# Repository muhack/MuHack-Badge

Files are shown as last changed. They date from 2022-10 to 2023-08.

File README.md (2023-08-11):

# MuHack-Badge
Official repository for MuHack Badge.

Badge startup

The board features an RP2040 as main microcontroller running micropython.
Its job is to setup and stream data from the Bosh Sensor Hub BHI106(B), as well as controlling the LEDs.

```Hardware/``` folder contains the KiCad project

```Software/``` folder contains the BOSS system and the sketches for the ESP32 (WIP)

> **NOTE: The software is still in development, so expect A LOT OF bugs and missing features.**

![Badge rotate](/image/rotate.gif)

## Chagelog v2

 - Added USB connector for the ESP32
 - Added NFC subsystem
 - Completely reworked the power system
 - Added more LEDs for battery status and esp32
 - Added a button for the ESP32
 - WIP: firmware update for better BHI support

## Chagelog v1
 - Initial release

## TODOs:
 - [x] Connect the interrupt line of BHI to the RP2040
 - [x] Invert TX/RX of UART between ESP32 and RP2040
 - [x] Change to a bigger footprint of ESP32 debug port
 - [x] Maybe add two button for boot sel and reset for the ESP32
 - [x] ~~Change~~ Remove battery switch
 - [x] Improve silkscreen text size
 - [x] Add silkscreen label for many things (pinout, battery polarity, etc)
 - [x] Expose BHI's internal I2C and interrupt line (for future sensors)
 - [x] Move I2C pull-up resistor
 - [x] Add leds and diods polarity
 - [x] Remove power inductor (or change to an available one)
 - [ ] ~~Maybe add a way to switch LEDs data line to the ESP32 instead of the RP2040~~
 - [ ] Docs and code comments
 - [x] Remove the D16 Schottky Diode from the battery line
 - [x] Maybe add some more cap to prevent brown-out when disconnecting USB power
 - [ ] Add a method within BHY library to stop every sensor
 - [x] Add NFC subsystem
 - [x] Add USB connector for the ESP32
  
 Special Thanks to:
 @gcammisa and Paolino

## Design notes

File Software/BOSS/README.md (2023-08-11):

# Badge Operating Small System

> **NOTE: The software is still in development, so expect A LOT OF bugs and missing features.**

The calibration process is still in development: there is a small utility to calibrate the sensor, but it is currently disabled from the headless mode.

## How to use

### Serial console
Simply connect the badge to your computer and connect to the serial port with a terminal emulator (e.g. `screen` or `minicom`).

### Headless mode
Turn the badge on without any USB data connection active and select the application you want to run.

Use the button "A" to select the application and the button "B" to start/stop it.

At the moment, there are 4 applications available:
- **Compass**: a simple compass that shows the current orientation of the badge, red arrow **should** points north
- **Accelerometer**: a simple accelerometer that shows the current acceleration on the 3 axis, the led on the "h" show the outwards direction, the led on the "u" show the inwards direction
- **Light show**: a simple light show, thank to the TrickLED library (to quit, reboot the badge)
- **Ball**: simulate the presence of a ball inside the led ring, using the accelerometer

If you leave the badge idle for around 200 seconds, it will automatically start the idle animation: simply pick it up or double tap on it to return to the menu.

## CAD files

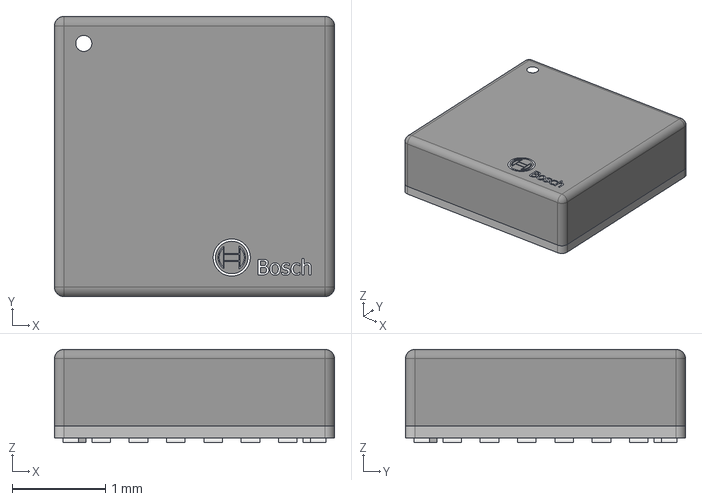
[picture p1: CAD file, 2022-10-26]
Hardware/IC_Bosch Sensortec_BHI160B/eec.models/Bosch_Sensortec_-_BHI160B.step
3.00 x 3.00 x 1.00 mm

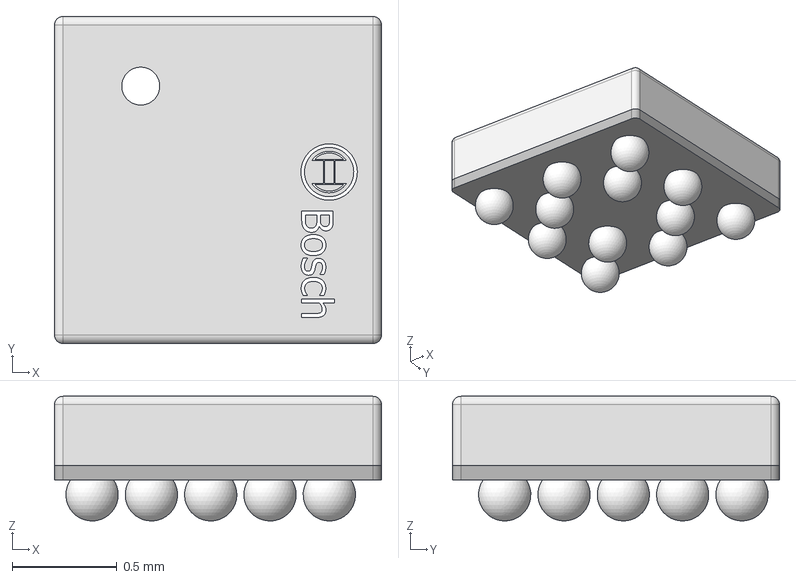
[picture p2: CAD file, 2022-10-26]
Hardware/IC_Bosch Sensortec_BMM150/eec.models/Bosch_Sensortec_-_BMM150.step
1.56 x 1.56 x 0.596 mm

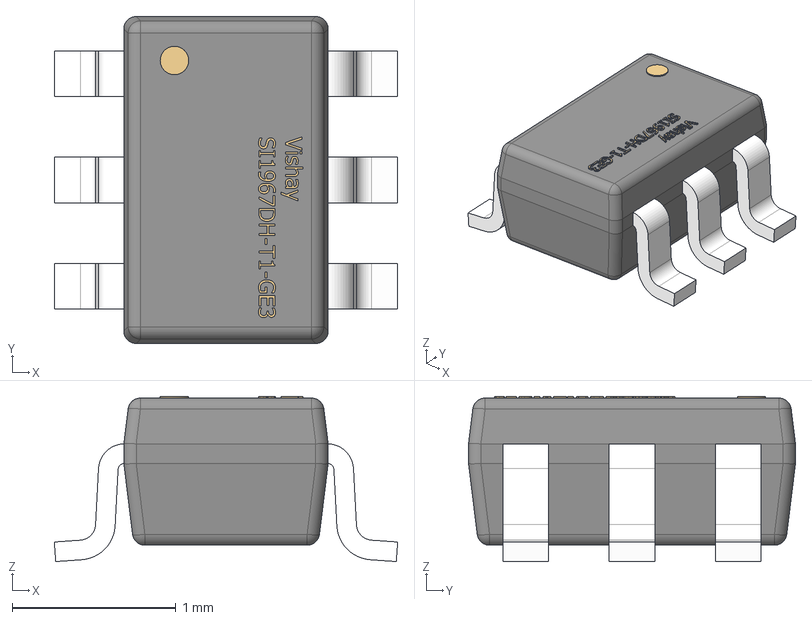
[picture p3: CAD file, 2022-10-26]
Hardware/Trans_Vishay_SI1967DH-T1-GE3/eec.models/Vishay_-_SI1967DH-T1-GE3.step
2.10 x 2.00 x 1.01 mm

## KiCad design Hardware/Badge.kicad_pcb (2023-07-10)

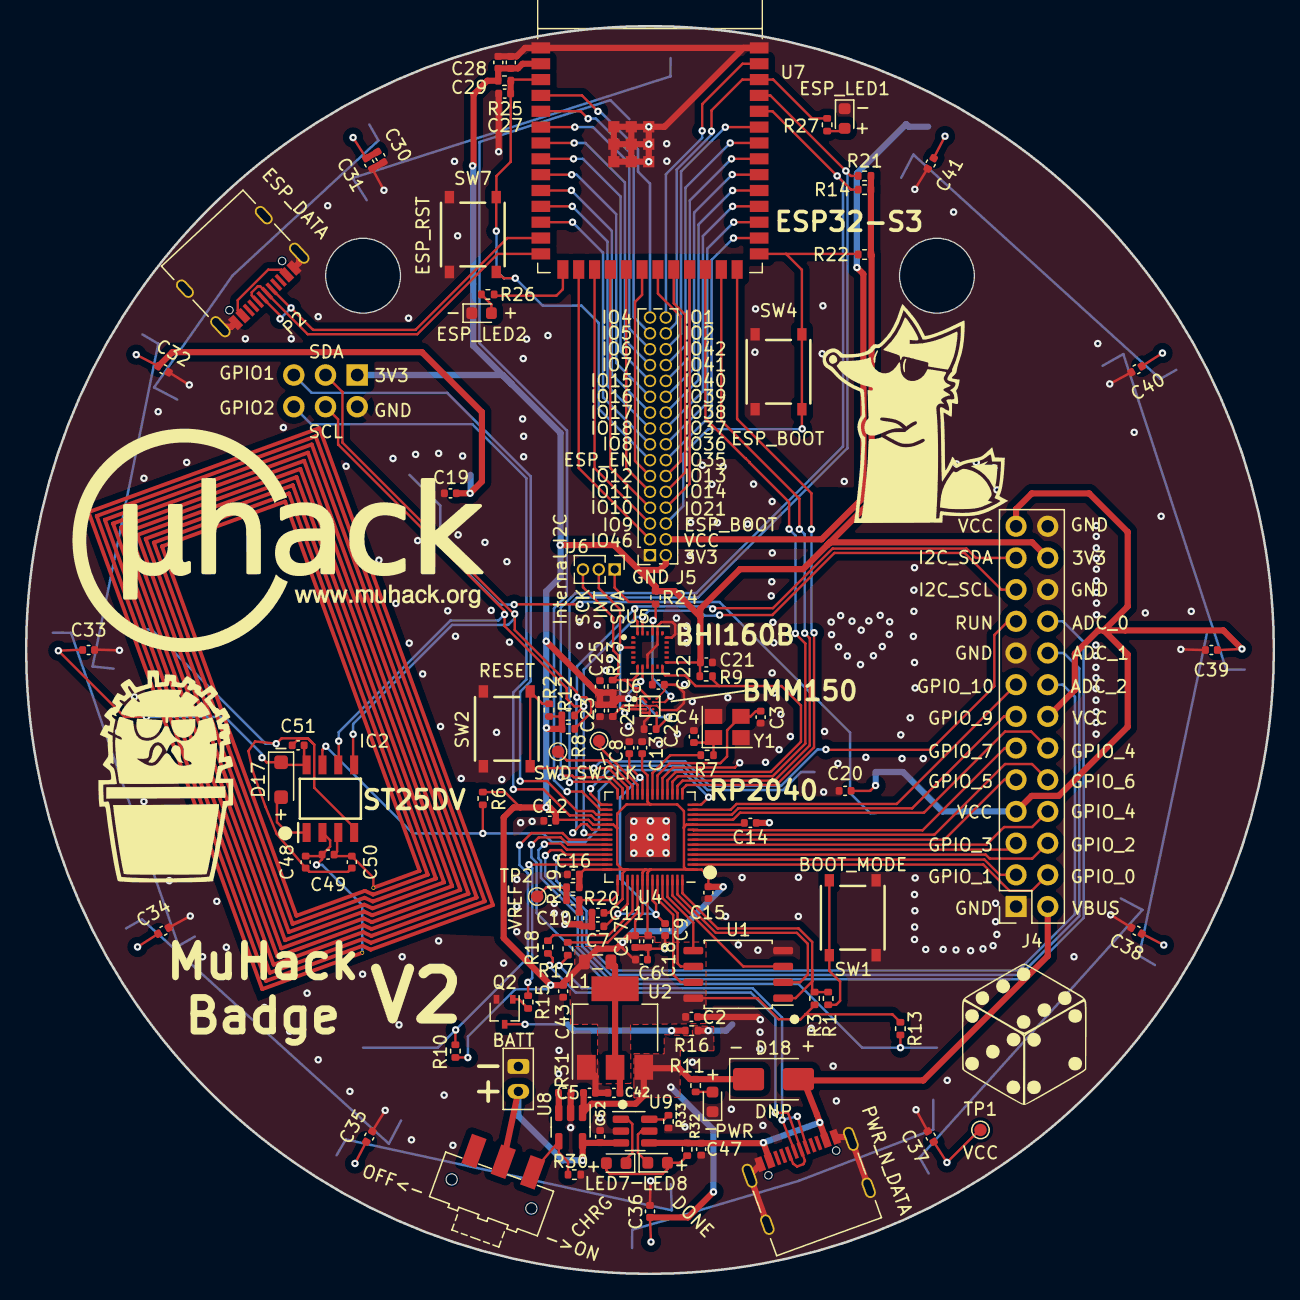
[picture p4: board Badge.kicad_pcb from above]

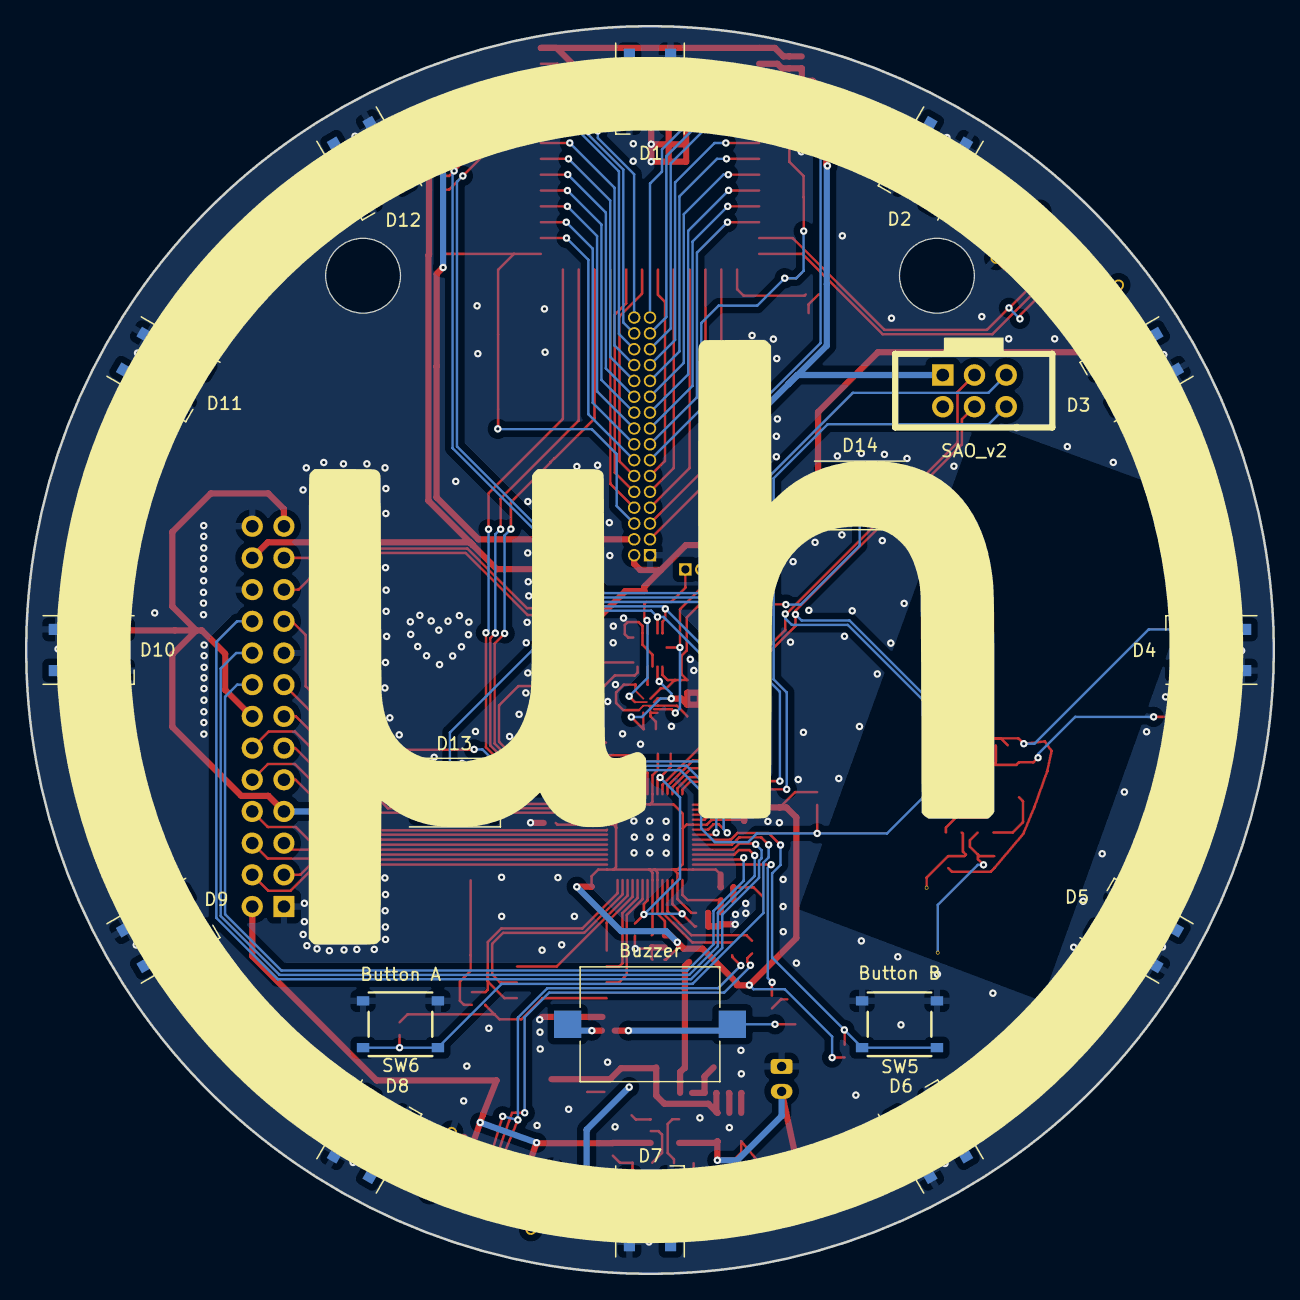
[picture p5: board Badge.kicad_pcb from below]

Board: 2 copper layers, 100.0 x 100.0 mm, 130 parts (18 on the bottom side), 119 nets.

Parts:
A1: MuTag_NFC_Antenna; muhack_badge_antenna
BT1: BATT; JST_PH_B2B-PH-K_1x02_P2.00mm_Vertical
BZ1: Buzzer; Buzzer_Mallory_AST1109MLTRQ
C2, C5, C6, C7, C8, C12, C13, C14, C15, C16, C17, C18, C21, C24, C25, C26, C29, C42: 100n; C_0402_1005Metric
C3, C4: 27p; C_0402_1005Metric
C9, C10, C11, C23, C27: 1u; C_0402_1005Metric
C19, C20, C28, C30, C31, C32, C33, C34, C35, C36, C37, C38, C39, C40, C41: 10u; C_0402_1005Metric
C22: 470n; C_0402_1005Metric
C43: 10n; C_0402_1005Metric
C47, C52: 4.7uF; C_0402_1005Metric
C48, C49, C50: DNP; C_0402_1005Metric
C51: 10nF; C_0402_1005Metric
D1, D2, D3, D4, D5, D6, D7, D8, D9, D10, D11, D12, D13, D14: WS2812B; LED_WS2812B_PLCC4_5.0x5.0mm_P3.2mm
D17: D; D_SOD-123F
D18: DNP; D_SMA
IC2: ST25DV; SOIC127P600X175-8N
J4: Conn_02x15_Counter_Clockwise; PinSocket_2x13_P2.54mm_Vertical
J5: Conn_01x12; PinSocket_2x16_P1.27mm_Vertical
J6: Internal_I2C; PinHeader_1x03_P1.27mm_Vertical
L1: 2.2uH; L_0805_2012Metric
LED2: ESP_LED2; LED_0603_1608Metric
LED3: PWR; LED_0603_1608Metric
LED4: ESP_LED1; LED_0603_1608Metric
LED7: CHRG; LED_0603_1608Metric
LED8: DONE; LED_0603_1608Metric
P1: PWR_N_DATA; USB_C_Receptacle_Palconn_UTC16-G
P2: ESP_DATA; USB_C_Receptacle_Palconn_UTC16-G
Q2: 2SC4213; SOT-323_SC-70
R1, R7, R32: 1k; R_0402_1005Metric
R2, R10, R13, R14, R21, R22, R25: 10k; R_0402_1005Metric
R3: DNF 10k; R_0402_1005Metric
R6, R8, R9, R12, R23, R24, R31: 4.7k; R_0402_1005Metric
R11, R26, R27: 470; R_0402_1005Metric
R15, R16, R33: 2k; R_0402_1005Metric
R17, R18, R19, R20: 27.4; R_0402_1005Metric
R30: 100k; R_0402_1005Metric
SW1: BOOT_MODE; TS-1187A-B-A-B
SW2: RESET; TS-1187A-B-A-B
SW4: ESP_BOOT; TS-1187A-B-A-B
SW5: Button B; TS-1187A-B-A-B
SW6: Button A; TS-1187A-B-A-B
SW7: ESP_RST; TS-1187A-B-A-B
SW9: PWR_SWT; SW_SPDT_CK-JS102011SAQN
TP1: VCC; TestPoint_Pad_D1.0mm
TP2: VREF; TestPoint_Pad_D1.0mm
TP3: SWCLK; TestPoint_Pad_D1.0mm
TP4: SWD; TestPoint_Pad_D1.0mm
U1: W25Q128JVS; SOIC-8_5.23x5.23mm_P1.27mm
U2: AMS1117-3.3; SOT-223-3_TabPin2
U4: RP2040; QFN-56-1EP_7x7mm_P0.4mm_EP3.2x3.2mm
U5: BHI160B; Bosch_Sensortec-BHI160B-MFG
U6: BMM150; Bosch_Sensortec-BMM150-IPC_B
U7: ESP32-S3; ESP32-S3-WROOM-1
U8: SY6280AAC; SOT-23-5
U9: TP4057; SOT-23-6
X1: SAO_v2; Simple_Addon_v2-BADGE-2x3
Y1: 12MHz_GND24; Crystal_SMD_3225-4Pin_3.2x2.5mm

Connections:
+1V1: C7.1, C8.1, C9.2, U4.23 (DVDD), U4.45 (VREG_VOUT), U4.50 (DVDD)
+3V3: C2.1, C6.2, C11.1, C12.2, C13.2, C14.2, C15.2, C16.2, C17.2, C18.2, C21.2, C23.1, C24.1, C25.2, C26.2, C28.1, C29.1, C43.2, J4.24, J5.2, L1.1, R2.2, R3.1, R6.1, R8.1, R9.1, R10.1, R12.1, R13.1, R14.2, R19.2, R21.2, R22.1, R23.1, R24.1, R25.1, U1.8 (VCC), U4.1 (IOVDD), U4.10 (IOVDD), U4.22 (IOVDD), U4.33 (IOVDD), U4.42 (IOVDD), U4.44 (VREG_IN), U4.48 (USB_VDD), U4.49 (IOVDD), U5.8 (VDDIO), U5.13 (VDD), U6.A1 (PS), U6.B2 (VDDIO), U6.E5 (VDD), U7.2 (3V3), X1.1 (3v3)
/ADC_0: J4.20, U4.38 (GPIO26_ADC0)
/ADC_1: J4.18, U4.39 (GPIO27_ADC1)
/ADC_2: J4.16, U4.40 (GPIO28_ADC2)
/ADC_AVDD: C10.1, R20.1, U4.43 (ADC_AVDD)
/ADC_BUZZ: R15.1, U4.41 (GPIO29_ADC3)
/ADC_VREF: R19.1, R20.2, TP2.1
/ESP_45: U4.15 (GPIO12), U7.26 (GPIO45)
/ESP_47: U4.17 (GPIO14), U7.24 (GPIO47/SPICLK_P/SUBSPICLK_P_DIFF)
/ESP_48: U4.16 (GPIO13), U7.25 (GPIO48/SPICLK_N/SUBSPICLK_N_DIFF)
/ESP_BOOT: J5.6, R22.2, SW4.2, U7.27 (GPIO0/BOOT)
/ESP_EN: C27.2, J5.13, R25.2, SW7.2, U7.3 (EN)
/ESP_RX: R14.1, U4.27 (GPIO16), U7.36 (U0RXD/GPIO44/CLK_OUT2)
/ESP_TX: R21.1, U4.28 (GPIO17), U7.37 (U0TXD/GPIO43/CLK_OUT1)
/GPIO_0: J4.4, U4.2 (GPIO0)
/GPIO_1: J4.3, U4.3 (GPIO1)
/GPIO_2: J4.6, U4.4 (GPIO2)
/GPIO_3: J4.5, U4.5 (GPIO3)
/GPIO_4: J4.8, U4.6 (GPIO4)
/GPIO_5: J4.9, U4.7 (GPIO5)
/GPIO_6: J4.10, U4.8 (GPIO6)
/GPIO_7: J4.11, U4.9 (GPIO7)
/GPIO_8: J4.12, U4.11 (GPIO8)
/GPIO_9: J4.13, U4.12 (GPIO9)
/GPIO_10: J4.15, U4.13 (GPIO10)
/Gyros/INT_S1: J6.2, U5.3 (GPIO1), U6.D2 (INT)
/Gyros/INT_SCK: J6.3, R23.2, U5.7 (ASCK), U6.A3 (SCK)
/Gyros/INT_SDA: J6.1, R24.2, U5.21 (ASDA), U6.B4 (SDI)
/I2C_SCL: IC2.6 (SCL), J4.21, R12.2, U4.35 (GPIO23), U5.23 (SCK), X1.4 (SCL)
/I2C_SDA: IC2.5 (SDA), J4.23, R8.2, U4.34 (GPIO22), U5.24 (SDA), X1.3 (SDA)
/LED_POST: D13.4 (DIN), U4.29 (GPIO18)
/LED_STRIPE: D1.4 (DIN), U4.30 (GPIO19)
/NFC/NFC_V_EH: D17.2 (A), IC2.1 (V_EH)
/NFC_INT: IC2.7 (GPO(OD)), R6.2, U4.14 (GPIO11)
/QSPI_SCLK: U1.6 (CLK), U4.52 (QSPI_SCLK)
/QSPI_SD0: U1.5 (DI(IO0)), U4.53 (QSPI_SD0)
/QSPI_SD1: U1.2 (DO(IO1)), U4.55 (QSPI_SD1)
/QSPI_SD2: U1.3 (IO2), U4.54 (QSPI_SD2)
/QSPI_SD3: U1.7 (IO3), U4.51 (QSPI_SD3)
/QSPI_SS: R1.2, R3.2, U1.1 (~CS), U4.56 (QSPI_SS)
/RUN: J4.19, R2.1, SW2.1, U4.26 (RUN)
/SAO_1: U4.31 (GPIO20), X1.5 (GPIO1)
/SAO_2: U4.32 (GPIO21), X1.6 (GPIO2)
/SEN_INT: R9.2, U4.18 (GPIO15), U5.12 (INT)
/SWCLK: TP3.1, U4.24 (SWCLK)
/SWD: TP4.1, U4.25 (SWD)
/SW_1: R10.2, SW5.2, U4.36 (GPIO24)
/SW_2: R13.2, SW6.2, U4.37 (GPIO25)
/USB_D+: P1.A6 (D+), P1.B6 (D+), R17.1
/USB_D-: P1.A7 (D-), P1.B7 (D-), R18.2
/WiFi_BT/ESP_USB+: P2.A6 (D+), P2.B6 (D+), U7.14 (GPIO20/U1CTS/ADC2_CH9/CLK_OUT1/USB_D+)
/WiFi_BT/ESP_USB-: P2.A7 (D-), P2.B7 (D-), U7.13 (GPIO19/U1RTS/ADC2_CH8/CLK_OUT2/USB_D-)
/WiFi_BT/IO1: J5.32, U7.39 (GPIO1/TOUCH1/ADC1_CH0)
/WiFi_BT/IO2: J5.30, R27.1, U7.38 (GPIO2/TOUCH2/ADC1_CH1)
/WiFi_BT/IO3: R26.1, U7.15 (GPIO3/TOUCH3/ADC1_CH2)
/WiFi_BT/IO4: J5.31, U7.4 (GPIO4/TOUCH4/ADC1_CH3)
/WiFi_BT/IO5: J5.29, U7.5 (GPIO5/TOUCH5/ADC1_CH4)
/WiFi_BT/IO6: J5.27, U7.6 (GPIO6/TOUCH6/ADC1_CH5)
/WiFi_BT/IO7: J5.25, U7.7 (GPIO7/TOUCH7/ADC1_CH6)
/WiFi_BT/IO8: J5.15, U7.12 (GPIO8/TOUCH8/ADC1_CH7/SUBSPICS1)
/WiFi_BT/IO9: J5.5, U7.17 (GPIO9/TOUCH9/ADC1_CH8/FSPIHD/SUBSPIHD)
/WiFi_BT/IO10: J5.7, U7.18 (GPIO10/TOUCH10/ADC1_CH9/FSPICS0/FSPIIO4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)
/WiFi_BT/IO11: J5.9, U7.19 (GPIO11/TOUCH11/ADC2_CH0/FSPID/FSPIIO5/S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)
/WiFi_BT/IO12: J5.11, U7.20 (GPIO12/TOUCH12/ADC2_CH1/FSPICLK/FSPIIO6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)
/WiFi_BT/IO13: J5.12, U7.21 (GPIO13/TOUCH13/ADC2_CH2/FSPIQ/FSPIIO7/S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)
/WiFi_BT/IO14: J5.10, U7.22 (GPIO14/TOUCH14/ADC2_CH3/FSPIWP/FSPIDQS/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)
/WiFi_BT/IO15: J5.23, U7.8 (GPIO15/U0RTS/ADC2_CH4/XTAL_32K_P)
/WiFi_BT/IO16: J5.21, U7.9 (GPIO16/U0CTS/ADC2_CH5/XTAL_32K_NH5)
/WiFi_BT/IO17: J5.19, U7.10 (GPIO17/U1TXD/ADC2_CH6)
/WiFi_BT/IO18: J5.17, U7.11 (GPIO18/U1RXD/ADC2_CH7/CLK_OUT3)
/WiFi_BT/IO21: J5.8, U7.23 (GPIO21)
/WiFi_BT/IO35: J5.14, U7.28 (SPIIO6/GPIO35/FSPID/SUBSPID)
/WiFi_BT/IO36: J5.16, U7.29 (SPIIO7/GPIO36/FSPICLK/SUBSPICLK)
/WiFi_BT/IO37: J5.18, U7.30 (SPIDQS/GPIO37/FSPIQ/SUBSPIQ)
/WiFi_BT/IO38: J5.20, U7.31 (GPIO38/FSPIWP/SUBSPIWP)
/WiFi_BT/IO39: J5.22, U7.32 (MTCK/GPIO39/CLK_OUT3/SUBSPICS1)
/WiFi_BT/IO40: J5.24, U7.33 (MTDO/GPIO40/CLK_OUT2)
/WiFi_BT/IO41: J5.26, U7.34 (MTDI/GPIO41/CLK_OUT1)
/WiFi_BT/IO42: J5.28, U7.35 (MTMS/GPIO42)
/WiFi_BT/IO46: J5.3, U7.16 (GPIO46)
/XIN: C3.2, U4.20 (XIN), Y1.3
/XOUT: R7.2, U4.21 (XOUT)
/~USB_BOOT: R1.1, SW1.2
GND: BT1.2 (-), C2.2, C3.1, C4.1, C5.1, C6.1, C7.2, C8.2, C9.1, C10.2, C11.2, C12.1, C13.1, C14.1, C15.1, C16.1, C17.1, C18.1, C19.2, C20.2, C21.1, C22.2, C23.2, C24.2, C25.1, C26.1, C27.1, C28.2, C29.2, C30.2, C31.2, C32.2, C33.2, C34.2, C35.2, C36.2, C37.2, C38.2, C39.2, C40.2, C41.2, C42.1, C43.1, C47.2, C48.1, C50.2, C51.2, C52.2, D1.3 (VSS), D2.3 (VSS), D3.3 (VSS), D4.3 (VSS), D5.3 (VSS), D6.3 (VSS), D7.3 (VSS), D8.3 (VSS), D9.3 (VSS), D10.3 (VSS), D11.3 (VSS), D12.3 (VSS), D13.3 (VSS), D14.3 (VSS), IC2.4 (VSS), J4.1, J4.17, J4.22, J4.26, J5.1, LED2.1 (K), LED3.1 (K), LED4.1 (K), P1.A1 (GND), P1.A12 (GND), P1.B1 (GND), P1.B12 (GND), P1.S1 (SHIELD), P2.A1 (GND), P2.A12 (GND), P2.B1 (GND), P2.B12 (GND), P2.S1 (SHIELD), Q2.2 (E), R30.1, R31.1, R33.1, SW1.1, SW2.2, SW4.1, SW5.1, SW6.1, SW7.1, U1.4 (GND), U2.1 (GND), U4.19 (TESTEN), U4.57 (GND), U5.9 (SA_GPIO7), U5.18 (GND), U5.20 (GNDIO), U6.A5 (CSB), U6.C1 (SDO), U6.C5 (GND), U6.E1 (GND), U6.E3 (GND), U7.1 (GND), U7.40 (GND), U7.41 (GND), U8.2 (GND), U9.2 (GND), X1.2 (GND), Y1.2, Y1.4
unnamed: A1.1 (IN), C48.2, C49.1, IC2.2 (AC0)
unnamed: A1.2 (OUT), C49.2, C50.1, IC2.3 (AC1)
unnamed: BT1.1 (+), C52.1, SW9.2 (B), U8.5 (IN), U9.3 (BAT)
unnamed: BZ1.2 (+), Q2.3 (C), R16.2
unnamed: C4.2, R7.1, Y1.1
unnamed: D1.2 (DOUT), D2.4 (DIN)
unnamed: D2.2 (DOUT), D3.4 (DIN)
unnamed: D3.2 (DOUT), D4.4 (DIN)
unnamed: D4.2 (DOUT), D5.4 (DIN)
unnamed: D5.2 (DOUT), D6.4 (DIN)
unnamed: D6.2 (DOUT), D7.4 (DIN)
unnamed: D7.2 (DOUT), D8.4 (DIN)
unnamed: D8.2 (DOUT), D9.4 (DIN)
unnamed: D9.2 (DOUT), D10.4 (DIN)
unnamed: D10.2 (DOUT), D11.4 (DIN)
unnamed: D11.2 (DOUT), D12.4 (DIN)
unnamed: D13.2 (DOUT), D14.4 (DIN)
unnamed: LED2.2 (A), R26.2
unnamed: LED3.2 (A), R11.2
unnamed: LED4.2 (A), R27.2
unnamed: LED7.2 (A), LED8.2 (A), R32.1
unnamed: LED7.1 (K), U9.1 (~CHRG)
unnamed: LED8.1 (K), U9.5 (~STDBY)
unnamed: P2.A4 (VBUS), P2.A9 (VBUS), P2.B4 (VBUS), P2.B9 (VBUS)
unnamed: Q2.1 (B), R15.2
unnamed: R30.2, SW9.1 (A), U8.4 (ON)
unnamed: C42.2, L1.2, U2.2 (VO)
unnamed: R18.1, U4.46 (USB_DM)
unnamed: R17.2, U4.47 (USB_DP)
unnamed: C22.1, U5.10 (VREG)
unnamed: R31.2, U8.3 (SET)
unnamed: R33.2, U9.6 (PROG)
VBUS: C47.1, D18.2 (A), J4.2, P1.A4 (VBUS), P1.A9 (VBUS), P1.B4 (VBUS), P1.B9 (VBUS), R32.2, U9.4 (VCC)
VCC: BZ1.1 (-), C5.2, C19.1, C20.1, C30.1, C31.1, C32.1, C33.1, C34.1, C35.1, C36.1, C37.1, C38.1, C39.1, C40.1, C41.1, C51.1, D1.1 (VDD), D2.1 (VDD), D3.1 (VDD), D4.1 (VDD), D5.1 (VDD), D6.1 (VDD), D7.1 (VDD), D8.1 (VDD), D9.1 (VDD), D10.1 (VDD), D11.1 (VDD), D12.1 (VDD), D13.1 (VDD), D14.1 (VDD), D17.1 (K), D18.1 (K), IC2.8 (VCC), J4.7, J4.14, J4.25, J5.4, R11.1, R16.1, TP1.1, U2.3 (VI), U8.1 (OUT)

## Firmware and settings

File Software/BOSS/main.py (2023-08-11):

# MuHack Badge BOSS firmware
# Copyright (C) 2021 MrMoDDoM
#
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
import sys
import time
#from time import sleep_ms
from machine import I2C, Pin, PWM, UART
from buzzer_music.buzzer_music import music
import binascii
import neopixel
import _thread
import gc
import micropython
import random
import os
import math

from BHY.bhy import BHY
from NFC.nfc import NFC
from CLED.cled import CLED

BOSS_Version = "2.0"

applications = []

autostart_file = "autostart.txt"

# We need a special buffer for the interrupts
micropython.alloc_emergency_exception_buf(100)

## I2C PINs ##
SCL_PIN = 23
SDA_PIN = 22
MAIN_I2C = I2C(1, scl=Pin(SCL_PIN), sda=Pin(SDA_PIN))
BHY_I2C_ADDR = 0x28 # 40 in decimal, should also respond to 45
NFC_I2C_ADDR = 0x53 # 83dec for access to user memory, Dynamic registers or Mailbox, 0x57 (87dec) for system area

## Interrupts PINs ##
NFC_INT_PIN = 11
BHI_INT_PIN = 15

## ESP32 communication PINs ##
ESP_TX_PIN = 16
ESP_RX_PIN = 17
ESP_COM_PIN_45 = 12
ESP_COM_PIN_48 = 13
ESP_COM_PIN_47 = 14

## Frontal RGB LED PINs ##
LED_LETTER_PIN = 18
LED_LETTER_LEN = 2

LED_STRIPE_PIN = 19
LED_STRIPE_LEN = 12

## Buzzer and Buttons PINs ##
BUZZER_PIN = 29
BUTTON_A_PIN = 25
BUTTON_B_PIN = 24

CLED_THREAD = 0

button_A = machine.Pin(BUTTON_A_PIN, Pin.IN)
button_B = machine.Pin(BUTTON_B_PIN, Pin.IN)

bhy = BHY(MAIN_I2C, address=BHY_I2C_ADDR, int_pin=BHI_INT_PIN, debug=False)
nfc = NFC(MAIN_I2C, address=NFC_I2C_ADDR, int_pin=NFC_INT_PIN, debug=False)
cled = CLED(LED_STRIPE_PIN, LED_STRIPE_LEN, LED_LETTER_PIN, LED_LETTER_LEN, debug=False)

## Startup chime ##
song = '0 E3 1 0;2 E4 1 0;4 E3 1 0;6 E4 1 0;8 E3 1 0;10 E4 1 0;12 E3 1 0;14 E4 1 0;16 A3 1 0;18 A4 1 0;20 A3 1 0;22 A4 1 0;24 A3 1 0;26 A4 1 0;28 A3 1 0;30 A4 1 0;32 G#3 1 0;34 G#4 1 0;36 G#3 1 0;38 G#4 1 0;40 E3 1 0;42 E4 1 0;44 E3 1 0;46 E4 1 0;48 A3 1 0;50 A4 1 0;52 A3 1 0;54 A4 1 0;56 A3 1 0;58 B3 1 0;60 C4 1 0;62 D4 1 0;64 D3 1 0;66 D4 1 0;68 D3 1 0;70 D4 1 0;72 D3 1 0;74 D4 1 0;76 D3 1 0;78 D4 1 0;80 C3 1 0;82 C4 1 0;84 C3 1 0;86 C4 1 0;88 C3 1 0;90 C4 1 0;92 C3 1 0;94 C4 1 0;96 G2 1 0;98 G3 1 0;100 G2 1 0;102 G3 1 0;104 E3 1 0;106 E4 1 0;108 E3 1 0;110 E4 1 0;114 A4 1 0;112 A3 1 0;116 A3 1 0;118 A4 1 0;120 A3 1 0;122 A4 1 0;124 A3 1 0;0 E6 1 1;4 B5 1 1;6 C6 1 1;8 D6 1 1;10 E6 1 1;11 D6 1 1;12 C6 1 1;14 B5 1 1;0 E5 1 6;4 B4 1 6;6 C5 1 6;8 D5 1 6;10 E5 1 6;11 D5 1 6;12 C5 1 6;14 B4 1 6;16 A5 1 1;20 A5 1 1;22 C6 1 1;24 E6 1 1;28 D6 1 1;30 C6 1 1;32 B5 1 1;36 B5 1 1;36 B5 1 1;37 B5 1 1;38 C6 1 1;40 D6 1 1;44 E6 1 1;48 C6 1 1;52 A5 1 1;56 A5 1 1;20 A4 1 6;16 A4 1 6;22 C5 1 6;24 E5 1 6;28 D5 1 6;30 C5 1 6;32 B4 1 6;36 B4 1 6;37 B4 1 6;38 C5 1 6;40 D5 1 6;44 E5 1 6;48 C5 1 6;52 A4 1 6;56 A4 1 6;64 D5 1 6;64 D6 1 1;68 D6 1 1;70 F6 1 1;72 A6 1 1;76 G6 1 1;78 F6 1 1;80 E6 1 1;84 E6 1 1;86 C6 1 1;88 E6 1 1;92 D6 1 1;94 C6 1 1;96 B5 1 1;100 B5 1 1;101 B5 1 1;102 C6 1 1;104 D6 1 1;108 E6 1 1;112 C6 1 1;116 A5 1 1;120 A5 1 1;72 A5 1 6;80 E5 1 6;68 D5 1 7;70 F5 1 7;76 G5 1 7;84 E5 1 7;78 F5 1 7;86 C5 1 7;88 E5 1 6;96 B4 1 6;104 D5 1 6;112 C5 1 6;120 A4 1 6;92 D5 1 7;94 C5 1 7;100 B4 1 7;101 B4 1 7;102 C5 1 7;108 E5 1 7;116 A4 1 7'

sensor_config = []
bhy_upload_try = 3
one_shot_re_enable = [BHY.VS_TYPE_WAKEUP,
                      BHY.VS_TYPE_WAKEUP + BHY.BHY_SID_WAKEUP_OFFSET,
                      BHY.VS_TYPE_GLANCE,
                      BHY.VS_TYPE_GLANCE + BHY.BHY_SID_WAKEUP_OFFSET,
                      BHY.VS_TYPE_PICKUP,
                      BHY.VS_TYPE_PICKUP + BHY.BHY_SID_WAKEUP_OFFSET]


## Remapping Matrix ##
# This matrix is used to remap the sensor data to the correct axis

#   | X | Y | Z |
# Xs| 1 | 0 | 0 |
# Ys| 0 | -1| 0 |
# Zs| 0 | 0 | -1|

#remapping_matrix = [0,1,0,1,0,0,0,0,-1] # P5 ?
#remapping_matrix = [1,0,0,0,-1,0,0,0,-1] # P7 ?
remapping_matrix = [1,0,0,0,1,0,0,0,-1] # P? ? - obtained from experimenting with the accelerometer

def testHardware():
    led_stripe = neopixel.NeoPixel(machine.Pin(LED_STRIPE_PIN), LED_STRIPE_LEN)
    led_letter = neopixel.NeoPixel(machine.Pin(LED_LETTER_PIN), LED_LETTER_LEN)
    try:
        print("Testing LED Stripe")
        for j in range(255):
            for i in range(LED_STRIPE_LEN):
                rc_index = (i * 256 // LED_STRIPE_LEN) + j
                led_stripe[i] = cled.wheel(rc_index & 255)
            led_stripe.write()
            time.sleep_ms(10)

        led_stripe.fill( (0,0,0) )
        led_stripe.write()    

        print("Testing LED on Letters")
        for j in range(255):
            for i in range(LED_LETTER_LEN):
                rc_index = (i * 256 // LED_LETTER_LEN) + j
                led_letter[i] = cled.wheel(rc_index & 255)
            led_letter.write()
            time.sleep_ms(10)

        led_letter.fill( (0,0,0) )
        led_letter.write()

        print("Testing A and B buttons")
        while True:
            if button_A.value():
                led_letter[0] = (255,0,0)
            else:
                led_letter[0] = (0,0,0)

            if button_B.value():
                led_letter[1] = (255,0,0)
            else:
                led_letter[1] = (0,0,0)

            if not button_A.value() and not button_B.value():
                break

            led_letter.write()

        print("Testing Buzzer")
        mySong = music(song, pins=[Pin(BUZZER_PIN)], looping=False)

        while mySong.tick():
            time.sleep_ms(40)

    except KeyboardInterrupt:
        print("##Hardware test aborted!##")
        return

    finally:
        led_stripe.fill( (0,0,0) )
        led_stripe.write()
        led_letter.fill( (0,0,0) )
        led_letter.write()

        # De-init the neopixel object
        del led_letter
        del led_stripe
        gc.collect()

def initBhy():
    print("Uploading firmware to BMI160")
    if not bhy.upload_BHI160B_RAM():
        print("Uploading FAILED!")
        return False

    print("Upload completed. Starting MainTask, waiting for the BMI160 to come up...")
    # print("int_status:", bhy.int_status)
    # while not bhy.bhy_interrupt():
    bhy.startMainTask()
    while not bhy.int_status:
        bhy.startMainTask()
        print(".", end='')
        pass

    time.sleep_ms(100)

    # And then we set the remapping matrix
    setRemappingMatrix()

    time.sleep_ms(100)
    return True

def printSensorsList():
    my_list = []
    for i in range(1,33): # TODO: find a more reliable way to find how many sensor are available
        my_list.append(str(i) + ". " + bhy.sensorIdToName(i))

    for a,b in zip(my_list[::2],my_list[1::2]):
        print ('{:<40}{:<}'.format(a,b))

def printSensorsConfig():
    if not len(sensor_config):
        print("No sensor configured yet!\n")
    else:
        for i in range(len(sensor_config)):
            print("-"*20)
            s = sensor_config[i]
            print((str(i)+". "), end='')
            print("Sensor name:", bhy.sensorIdToName(s["sensor_id"]))
            print("\tWakeup:",s["wakeup_status"])
            print("\tSample rate:",s["sample_rate"])
            print("\tLatency ms:",s["max_report_latency_ms"])
            print("\tFlush FIFO:", end='')
            if s["flush_sensor"] == BHY.BHY_FIFO_FLUSH_ALL:
                print(" BHY_FIFO_FLUSH_ALL")
            else:
                print(" NONE")
            print("\tChange sensitivity:",s["change_sensitivity"])
            print("\tDynamic range:",s["dynamic_range"])
            print("-"*20)

    print('\n')

# Typical configuration is:
# Wakeup: FALSE
# Sample freq: 25 Hz
# Flush FIFO sensor: FALSE
# Max Report Latency: 0
# Change Sensitivity: 0
# Dynamic Range: 0

def addNewSensor():
    printSensorsList()
    id = int(input("Sensor ID: "))
    wake = input("Wakeup? [y/N]: ")
    sample = int(input("Sample rate [25]: ") or 25)
    latency = int(input("Max report latency [0]: ") or 0)
    flush_sensor = str(input("Flush Sensor data [-A-ll/-n-one]: ") or "A")
    change_sensitivity = int(input("Change Sensitivity [0]: ") or 0)
    dynamic_range = int(input("Dynamic Range [0]: ") or 0)

    if wake == 'y' or wake == 'Y':
        wake = True
    else:
        wake = False

    if flush_sensor == 'a' or flush_sensor == 'A':
        flush_sensor = BHY.BHY_FIFO_FLUSH_ALL
    else:
        flush_sensor = 0

    sensor_config.append({"sensor_id": id,
                          "wakeup_status": wake,
                          "sample_rate":sample,
                          "max_report_latency_ms": latency,
                          "flush_sensor": flush_sensor,
                          "change_sensitivity": change_sensitivity,
                          "dynamic_range": dynamic_range,
                          "to_remove": False})

    print("Sensor added!\n")

def removeSensor():
    printSensorsConfig()
    id = int(input("Sensor ID:"))
    if id >= len(sensor_config):
        print("Not a valid choice!")
    else:
        s = sensor_config[id]
        bhy.configVirtualSensor(s["sensor_id"], s["wakeup_status"], 0, 0, 0, 0, 0) # To disable a sensor, set sample reat at 0
        sensor_config.remove(s)
        print("Sensor Removed!\n")

def sensorsMenu():
    fin = False
    while not fin:
        print("### Sensors Menu ###")
        print("1. Print current configuration")
        print("2. Add a new sensor")
        print("3. Remove a sensor")
        print("4. Scan Physical Sensors")
        print("5. Calibrate Sensors")
        print("\n99. Return main menu")

        sel = input("\n> ")
        if sel == "1":
            printSensorsConfig()
        elif sel == "2":
            addNewSensor()
        elif sel == "3":
            removeSensor()
        elif sel == "4":
            scanPhysicalSensor()
        elif sel == "5":
            calibrationProccess()
        elif sel == "99":
            fin = True
        else:
          print("Bad selection!\n")

def scanPhysicalSensor():
    for i in range(33,96):
        data = bhy.readParameterPage(bhy.BHY_SYSTEM_PAGE, i, 16)
        if data:
            print("-"*20)
            print(binascii.hexlify(data))
            print("-"*20)

# TODO: Fix this function and add physical sensor query procedure
def discoverSelfTest():
    bhy.requestSelfTest()
    # Wait for interrupt
    while not bhy.bhy_interrupt():
        pass

    buffer = bhy.readFIFO()

    #print(binascii.hexlify(buffer))

    # print("Event type:", info,
    #     "\tEvent ID:", buffer[0],
    #     "\tData:", binascii.hexlify(buffer[:dim])
    #     )

    # events = bhy.parse_fifo(buffer, [BHY.EV_META_EVENTS, BHY.EV_WAKEUP_META_EVENTS])
    # for e in events:
    #     print(bhy.parseMetaEvent(e[2]))

def streamCalibration(vs_type):
    calibrated = False
    calibration_level = -1
    try:
        while not calibrated:
            # Wait for interrupt
            while not bhy.bhy_interrupt():
                pass

            buffer = bhy.readFIFO()

            events = bhy.parse_fifo(buffer, raw=True) # Dont pass the filters if we want to show everythings

            for e in events: # Loop every events read
                if e[0] == vs_type:
                    actual_level = bhy.parseVectorPlus(e[2])["accuracy"]
                    if actual_level > calibration_level:
                        calibration_level = actual_level
                        cled.drawLevel(actual_level, 3)
                        print("Level of calibration:", calibration_level)

            if calibration_level == 3:
                calibrated = True
                cled.blinkAll((255,255,255), 50, 2)
                print("Calibrated!")

        return True

    except KeyboardInterrupt:
        print("User Interrupt! Ending streaming!")
        return False

def setRemappingMatrix():
    print("Current Accelerometer map is:")
    print(bhy.getRemappingMatrix(BHY.VS_TYPE_ACCELEROMETER))
    bhy.setRemappingMatrix(BHY.VS_TYPE_ACCELEROMETER, remapping_matrix)
    print("New Accelerometer map is:")
    print(bhy.getRemappingMatrix(BHY.VS_TYPE_ACCELEROMETER))
    print("Current Megnetometer map is:")
    print(bhy.getRemappingMatrix(BHY.VS_TYPE_MAGNETIC_FIELD_UNCALIBRATED))
    bhy.setRemappingMatrix(BHY.VS_TYPE_MAGNETIC_FIELD_UNCALIBRATED, remapping_matrix)
    print("New Megnetometer map is:")
    print(bhy.getRemappingMatrix(BHY.VS_TYPE_MAGNETIC_FIELD_UNCALIBRATED))
    print("Current Gyroscope map is:")
    print(bhy.getRemappingMatrix(BHY.VS_TYPE_GYROSCOPE_UNCALIBRATED))
    bhy.setRemappingMatrix(BHY.VS_TYPE_GYROSCOPE_UNCALIBRATED, remapping_matrix)
    print("New Gyroscope map is:")
    print(bhy.getRemappingMatrix(BHY.VS_TYPE_GYROSCOPE_UNCALIBRATED))

def calibrationProccess():
    bhy.calibrated = False

    print("##This procedure will follow you to calibrate the BHI160B sensors##")
    print("\nFirst we set the remapping Matrix for the MuHack Badge pcb...")
    setRemappingMatrix()
    print("\nThen, starting from the gyroscope, lay the pcb on a flat surface:")

    bhy.configVirtualSensorWithConfig({"sensor_id": BHY.VS_TYPE_GYROSCOPE,
                                       "wakeup_status": False,
                                       "sample_rate": 200,
                                       "max_report_latency_ms": 0,
                                       "flush_sensor": 0,
                                       "change_sensitivity": 0,
                                       "dynamic_range": 0
                                       })

    if not streamCalibration(BHY.VS_TYPE_GYROSCOPE):
        print("\n##Calibration process ABORTED##\n")
        return False

    # Disable the Gyroscope
    bhy.configVirtualSensorWithConfig({"sensor_id": BHY.VS_TYPE_GYROSCOPE,
                                       "wakeup_status": False,
                                       "sample_rate": 0,
                                       "max_report_latency_ms": 0,
                                       "flush_sensor": 0,
                                       "change_sensitivity": 0,
                                       "dynamic_range": 0
                                       })
    print("Now the Accelerometer: rotate the board with 45° step in one direction")

    bhy.configVirtualSensorWithConfig({"sensor_id": BHY.VS_TYPE_ACCELEROMETER,
                                       "wakeup_status": False,
                                       "sample_rate": 200,
                                       "max_report_latency_ms": 0,
                                       "flush_sensor": 0,
                                       "change_sensitivity": 0,
                                       "dynamic_range": 0
                                       })
    if not streamCalibration(BHY.VS_TYPE_ACCELEROMETER):
        print("\n##Calibration process ABORTED##\n")
        return False

    # Disable the Accelerometer
    bhy.configVirtualSensorWithConfig({"sensor_id": BHY.VS_TYPE_ACCELEROMETER,
                                       "wakeup_status": False,
                                       "sample_rate": 0,
                                       "max_report_latency_ms": 0,
                                       "flush_sensor": 0,
                                       "change_sensitivity": 0,
                                       "dynamic_range": 0
                                       })

    print("And last, the Magnetometer: draw an 8-figure in mid-air with the board")
    bhy.configVirtualSensorWithConfig({"sensor_id": BHY.VS_TYPE_GEOMAGNETIC_FIELD,
                                       "wakeup_status": False,
                                       "sample_rate": 200,
                                       "max_report_latency_ms": 0,
                                       "flush_sensor": 0,
                                       "change_sensitivity": 0,
                                       "dynamic_range": 0
                                       })
    if not streamCalibration(BHY.VS_TYPE_GEOMAGNETIC_FIELD):
        print("\n##Calibration process ABORTED##\n")
        return False

    # Disable the Magnetometer
    bhy.configVirtualSensorWithConfig({"sensor_id": BHY.VS_TYPE_GEOMAGNETIC_FIELD,
                                       "wakeup_status": False,
                                       "sample_rate": 0,
                                       "max_report_latency_ms": 0,
                                       "flush_sensor": 0,
                                       "change_sensitivity": 0,
                                       "dynamic_range": 0
                                       })

    print("\n##Calibration completed!##\n")
    bhy.calibrated = True
    cled.clear()
    cled.np.write()

def idleAnimation():
    # startCLED() # We dont need CLED on idle
        # Activate orientation sensor
    sensor = {"sensor_id": BHY.VS_TYPE_PICKUP,
              "wakeup_status": True,
              "sample_rate": 200,
              "max_report_latency_ms": 0,
              "flush_sensor": 0,
              "change_sensitivity": 0,
              "dynamic_range": 0
             }
    bhy.configVirtualSensorWithConfig(sensor)

    sensor = {"sensor_id": BHY.VS_TYPE_WAKEUP,
              "wakeup_status": True,
              "sample_rate": 200,
              "max_report_latency_ms": 0,
              "flush_sensor": 0,
              "change_sensitivity": 0,
              "dynamic_range": 0
             }
    bhy.configVirtualSensorWithConfig(sensor)

    startCLED()

    j = 0

    fin = False

    try:
        while not fin:
            gc.collect()

            if (not button_A.value()):
                break

            # Wait for interrupt and progress the animation
            while not bhy.bhy_interrupt():
                for i in range(LED_STRIPE_LEN):
                    rc_index = (i * 256 // LED_STRIPE_LEN) + j
                    cled.np[i] = cled.wheel(rc_index & 255)

                for i in range(LED_LETTER_LEN):
                    rc_index = (i * 256 // LED_LETTER_LEN) + j
                    cled.np_letter[i] = cled.wheel(rc_index & 255)

                cled.np.write()
                cled.np_letter.write()
                time.sleep_ms(10)

                j += 1
                if j >= 255:
                    j = 0

            buffer = bhy.readFIFO()

            events = bhy.parse_fifo(buffer, False) # Dont pass the filters if we want to show everythings

            for e in events: # Loop every events read
                if (e[0] == BHY.VS_TYPE_PICKUP 
                    or e[0] == (BHY.VS_TYPE_PICKUP + BHY.BHY_SID_WAKEUP_OFFSET)
                    or e[0] == BHY.VS_TYPE_WAKEUP 
                    or e[0] == (BHY.VS_TYPE_WAKEUP + BHY.BHY_SID_WAKEUP_OFFSET)):
                    fin = True # We have been picked up!

    except Exception as e:
        raise e
    finally:
        stopCLED()
        # Disable orientation sensor
        sensor["sample_rate"] = 0
        bhy.configVirtualSensorWithConfig(sensor)
        cled.clear()
        cled.clearLetter()
        cled.np.write()
        cled.np_letter.write()

def accelerometer():
    # Activate orientation sensor
    sensor = {"sensor_id": BHY.VS_TYPE_LINEAR_ACCELERATION,
              "wakeup_status": False,
              "sample_rate": 25,
              "max_report_latency_ms": 0,
              "flush_sensor": 0,
              "change_sensitivity": 0,
              "dynamic_range": 0
             }
    bhy.configVirtualSensorWithConfig(sensor)

    startCLED()

    try:
        while True:
            if (not button_B.value()):
                break
            gc.collect()

            # Wait for interrupt
            while not bhy.bhy_interrupt():
                pass

            buffer = bhy.readFIFO()

            events = bhy.parse_fifo(buffer, False) # Dont pass the filters if we want to show everythings

            for e in events: # Loop every events read
                if e[0] == BHY.VS_TYPE_LINEAR_ACCELERATION or e[0] == (BHY.VS_TYPE_LINEAR_ACCELERATION + BHY.BHY_SID_WAKEUP_OFFSET):
                    cled.addAnimation(cled.ANIM_DRAW_VECTOR, [(e[2]['x'] * 16 ) / 32768, (e[2]['y'] * 16 ) / 32768, (e[2]['z'] * 16 ) / 32768, 10])
                    
    except Exception as e:
        raise e
    finally:
        stopCLED()
        # Disable orientation sensor
        sensor["sample_rate"] = 0
        bhy.configVirtualSensorWithConfig(sensor)
        
def compass():
    # Activate orientation sensor
    sensor = {"sensor_id": BHY.VS_TYPE_ORIENTATION,
              "wakeup_status": False,
              "sample_rate": 25,
              "max_report_latency_ms": 0,
              "flush_sensor": 0,
              "change_sensitivity": 0,
              "dynamic_range": 0
             }
    bhy.configVirtualSensorWithConfig(sensor)

    startCLED()

    try:
        while True:
            if (not button_B.value()):
                break
            gc.collect()

            # Wait for interrupt
            while not bhy.bhy_interrupt():
                pass

            buffer = bhy.readFIFO()

            events = bhy.parse_fifo(buffer, False) # Dont pass the filters if we want to show everythings

            for e in events: # Loop every events read
                if e[0] == BHY.VS_TYPE_ORIENTATION or e[0] == (BHY.VS_TYPE_ORIENTATION + BHY.BHY_SID_WAKEUP_OFFSET):
                    north = 360 - e[2]['x'] # Lock in place the rotation 
                    cled.addAnimation(cled.ANIM_DRAW_ARROW, north)
                    
    except Exception as e:
        raise e
    finally:
        stopCLED()
        # Disable orientation sensor
        sensor["sample_rate"] = 0
        bhy.configVirtualSensorWithConfig(sensor)
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

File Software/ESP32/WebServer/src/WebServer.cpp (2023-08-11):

#include <Arduino.h>
#include <ArduinoOTA.h>
// #include <Uri.h>
// #include <WebServer.h>
// #include <HTTP_Method.h>
#include <FS.h>
#include <SPIFFS.h>

/* You only need to format SPIFFS the first time you run a
   test or else use the SPIFFS plugin to create a partition
   https://github.com/me-no-dev/arduino-esp32fs-plugin */
#define FORMAT_SPIFFS_IF_FAILED true
//#include <ESPmDNS.h>

#include <ESPAsyncWebServer.h>
#include <AsyncTCP.h>
#include <WiFi.h>

#include "SerialCommander.h"
#include "WebHandlers.h"
#include "WebSocket.cpp"

const char* ssid = "SSID";
const char* password = "PASSWORD";
const char* host = "MuHack-Badge";

AsyncWebServer server(80);  // Object of WebServer(HTTP port, 80 is defult)
AsyncWebSocket ws("/ws");

SerialCommander serialCommander;

void setup() {
  Serial.begin(115200);
  Serial.println("Booting");
  WiFi.mode(WIFI_STA);
  WiFi.begin(ssid, password);
  bool fin = false;
  while (!fin) {
    if(WiFi.waitForConnectResult() == WL_CONNECTED){
      fin = true;
      break;
    }
    Serial.println("Connection Failed! I'll keep trying (press a key to change wifi credentials..");
    delay(1000);
    if (Serial.available() > 0) { // TODO: fix all this mess
      Serial.print("SSID: ");
      String new_ssid = Serial.readString();
      Serial.print("ESP32 received: ");
      Serial.println(new_ssid);
      Serial.print("Password: ");
      String new_password = Serial.readString();
      Serial.print("ESP32 received: ");
      Serial.println(new_password);
      WiFi.begin(new_ssid.c_str(), new_password.c_str());
    }
    delay(5000);
    //ESP.restart();
  }

  WiFi.setHostname(host);

  // Port defaults to 3232
  // ArduinoOTA.setPort(3232);

  // Hostname defaults to esp3232-[MAC]

  // No authentication by default
  // ArduinoOTA.setPassword("admin");

  // Password can be set with it's md5 value as well
  // MD5(admin) = 21232f297a57a5a743894a0e4a801fc3
  // ArduinoOTA.setPasswordHash("21232f297a57a5a743894a0e4a801fc3");

  Serial.println("Init SPIFFS");
  // Initialize SPIFFS
  if(!SPIFFS.begin(FORMAT_SPIFFS_IF_FAILED)){
    Serial.println("An Error has occurred while mounting SPIFFS");
    ESP.restart();
  }

  ArduinoOTA
    .onStart([]() {
      String type;
      if (ArduinoOTA.getCommand() == U_FLASH)
        type = "sketch";
      else // U_SPIFFS
        type = "filesystem";

      // NOTE: if updating SPIFFS this would be the place to unmount SPIFFS using SPIFFS.end()
      Serial.println("Start updating " + type);
      SPIFFS.end();
    })
    .onEnd([]() {
      Serial.println("\nEnd");
    })
    .onProgress([](unsigned int progress, unsigned int total) {
      Serial.printf("Progress: %u%%\r", (progress / (total / 100)));
    })
    .onError([](ota_error_t error) {
      Serial.printf("Error[%u]: ", error);
      if (error == OTA_AUTH_ERROR) Serial.println("Auth Failed");
      else if (error == OTA_BEGIN_ERROR) Serial.println("Begin Failed");
      else if (error == OTA_CONNECT_ERROR) Serial.println("Connect Failed");
      else if (error == OTA_RECEIVE_ERROR) Serial.println("Receive Failed");
      else if (error == OTA_END_ERROR) Serial.println("End Failed");
    });

  ArduinoOTA.begin();

  Serial.println("Ready");
  Serial.print("IP address: ");
  Serial.println(WiFi.localIP());

  ws.onEvent(onWsEvent);
  server.addHandler(&ws);


  // Server with different default file
  server.serveStatic("/", SPIFFS, "/data/").setDefaultFile("index.html");
  // Start the web server
  // server.on("/", HTTP_GET, [](AsyncWebServerRequest *request){
  //   request->send(SPIFFS, "/index.html");
  // });
  // server.on("/ledGreen", handle_ledGreen);
  // server.on("/drawVector", handle_drawVector);
  auto handler = server.on("/drawVector", [](AsyncWebServerRequest *request){
    handle_drawVector(request);
  });
  // server.on("/sensor", handle_Sensor);
  server.onNotFound(handle_NotFound);

  server.begin();
  Serial.println("HTTP server started");
}

void loop() {
  ws.cleanupClients();
  ArduinoOTA.handle();

  String command = "";
  while (Serial.available() > 0) {
      command += (char)Serial.read();
  }
  if (command != "") {
    Serial.println("Received: " + command);
  }
  
}

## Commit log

2022-10-26 First Commit - version 1.0
    [Badge.kicad_pcb, Badge.kicad_sch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]
2022-10-27 Added SAOv2 Connector - re-arranged some RP pins connection
    [Badge.kicad_pcb, Badge.kicad_sch]
2022-10-27 Connected both USB-C data signal, moved the crystal - revisisted ready for production
    [Badge-CuBottom.gbr, Badge-CuTop.gbr, Badge-EdgeCuts.gbr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]
2022-11-24 First BOSS commit, added BasicOTA (not working), updated Hardware .gitignore
    [cled.py, example.py, main.py]
2022-11-25 Improved the headless mode, CLED system and minor bug fix - UNSATBLE
    [cled.py, main.py]
2022-11-25 Headless mode is working, added idle animation - there are still some bugs with CLED
    [cled.py, main.py]
2023-04-03 Inverted TX/RX from ESP32 - added INT line from BHI - Changed ESP32 dbg port to bigger footprint
    [Badge.kicad_pcb, Badge.kicad_sch, Cirle_led.kicad_sch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]
2023-06-22 First modification for v2
    [Badge.kicad_pcb, Badge.kicad_sch, Gyros.kicad_sch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]
2023-06-28 WIP - Added NFC Antenna and connected almost everythings else
    [Badge.kicad_pcb, Badge.kicad_sch, NFC.kicad_sch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]
2023-06-29 All upgrade done, start working on lesser stuff (like silkscreen)
    [Badge.kicad_pcb, Badge.kicad_sch, WiFi_BT.kicad_sch]
2023-06-30 TODO list completed - need to search for components
    [Badge.kicad_pcb, Badge.kicad_sch, NFC.kicad_sch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]
2023-07-06 Testing with different power circuit
    [Badge.kicad_pcb, Badge.kicad_sch]
2023-07-06 Ready to order - THE POWER DIODE IS MISSING (need futher investigations)
    [Badge-CuBottom.gbr, Badge-CuTop.gbr, Badge-EdgeCuts.gbr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]
2023-07-10 Reworked the power system - ORDERED ON JLCPCB
    [Badge-CuBottom.gbr, Badge-CuTop.gbr, Badge-EdgeCuts.gbr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]
2023-08-02 Added trickLED animation - fixed some bug - SENSORS DONT WORK
    [main.py, nfc.py]
2023-08-04 Resolved the BHI160 problem: all sensors and headless mode working - First draft for NFC wakeup from deepsleep (NOT WORKING)
    [main.py, nfc.py]
2023-08-10 Working ball program - but the headless version crashes when it is launched
    [main.py, nfc.py]
2023-08-11 Bug fix for headless ball program - added header license to files - add license for trickLED - cleared boot and autostart procedure
    [cled.py, main.py]

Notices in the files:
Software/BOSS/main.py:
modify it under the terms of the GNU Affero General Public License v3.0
